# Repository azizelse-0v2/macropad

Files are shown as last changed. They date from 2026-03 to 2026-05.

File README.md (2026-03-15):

# Macro Pad

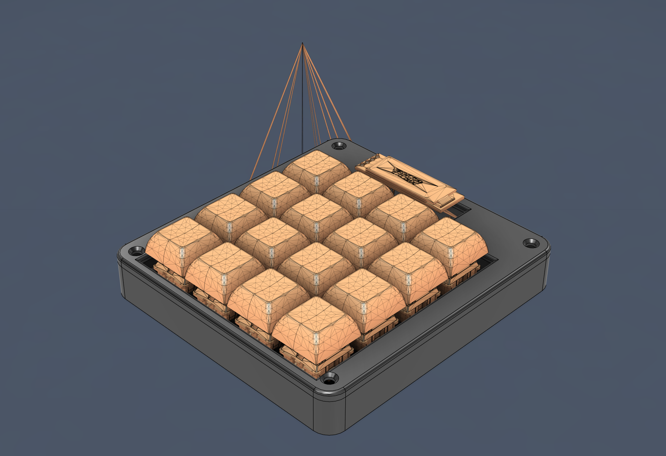
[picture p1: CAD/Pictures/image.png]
Macro Pad


A custom macro pad featuring 16 mechanical switches, OLED display, and RGB LEDs. Built with the Seeed XIAO RP2040 microcontroller and KMK firmware for a compact, programmable keyboard solution.

## Features

- **4 Cherry MX Switches**: Tactile mechanical switches for responsive key presses
- **0.96" OLED Display**: SH1106 I2C display for status or custom graphics
- **RGB LED Matrix**: WS2812B LEDs for visual feedback
- **Compact Design**: Fits within 200x200x100mm enclosure
- **KMK Firmware**: Python-based firmware for easy customization

## Images

### Schematic
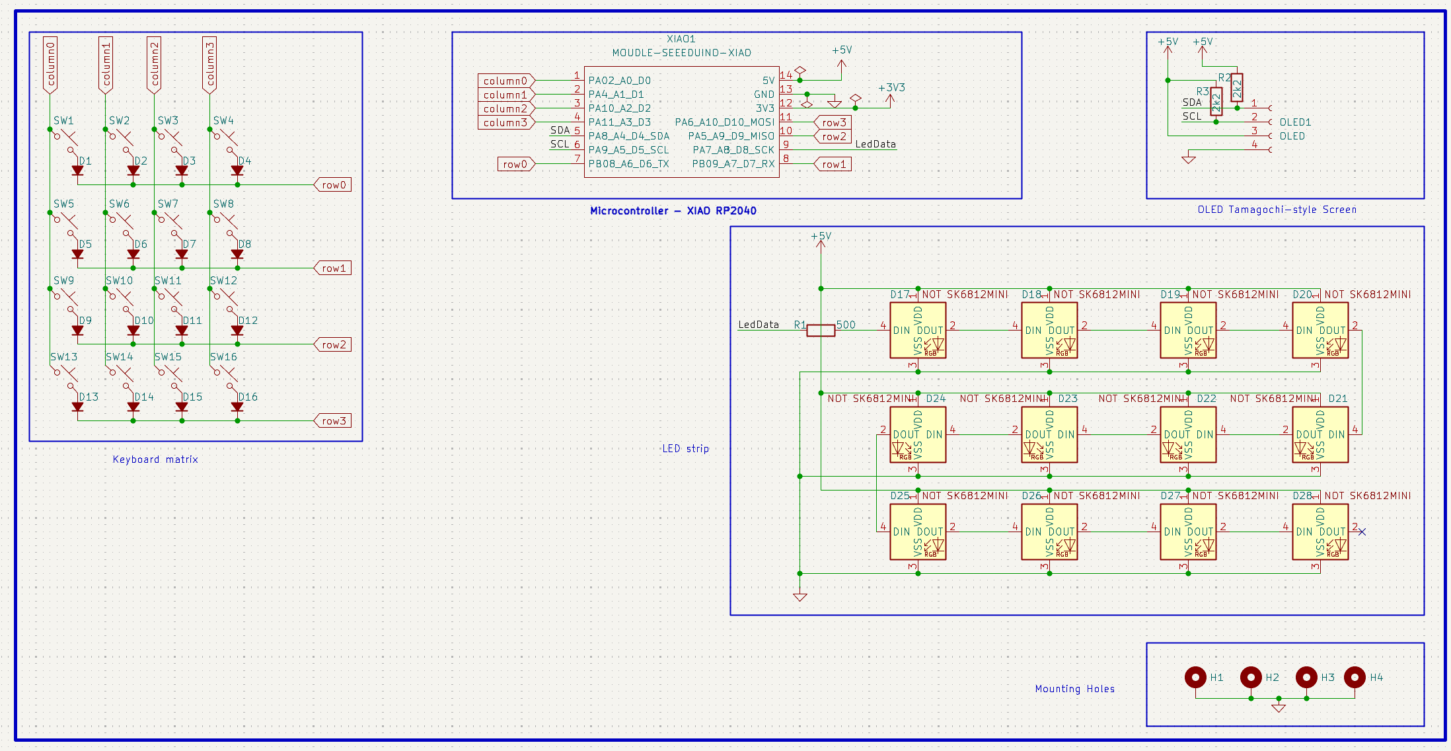
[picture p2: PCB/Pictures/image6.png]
Schematic


### PCB Layout
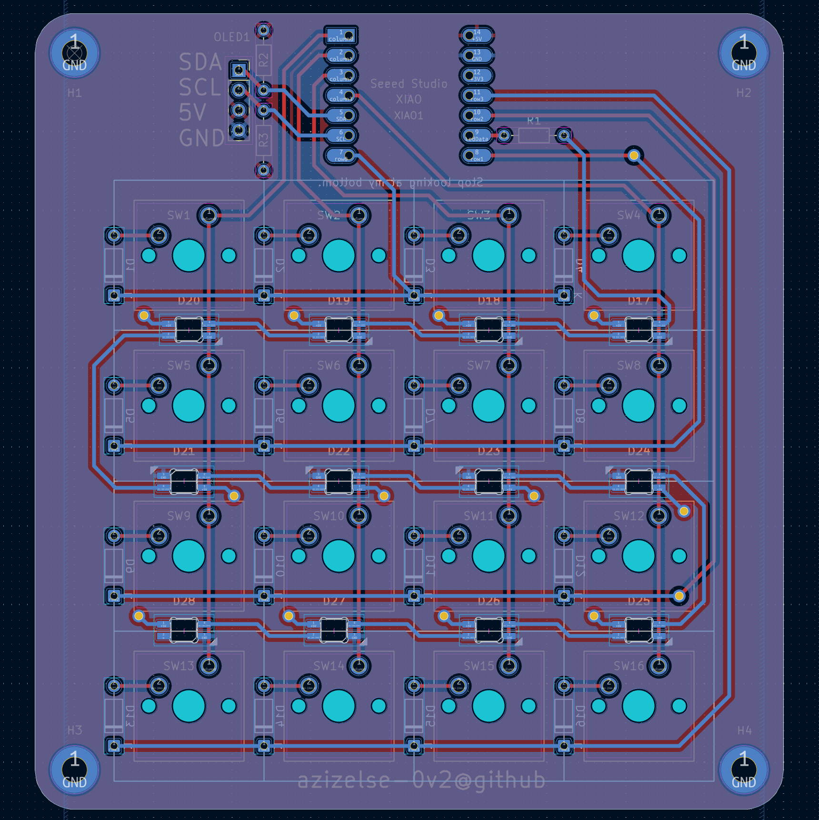
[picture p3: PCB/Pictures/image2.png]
PCB


### Case Assembly
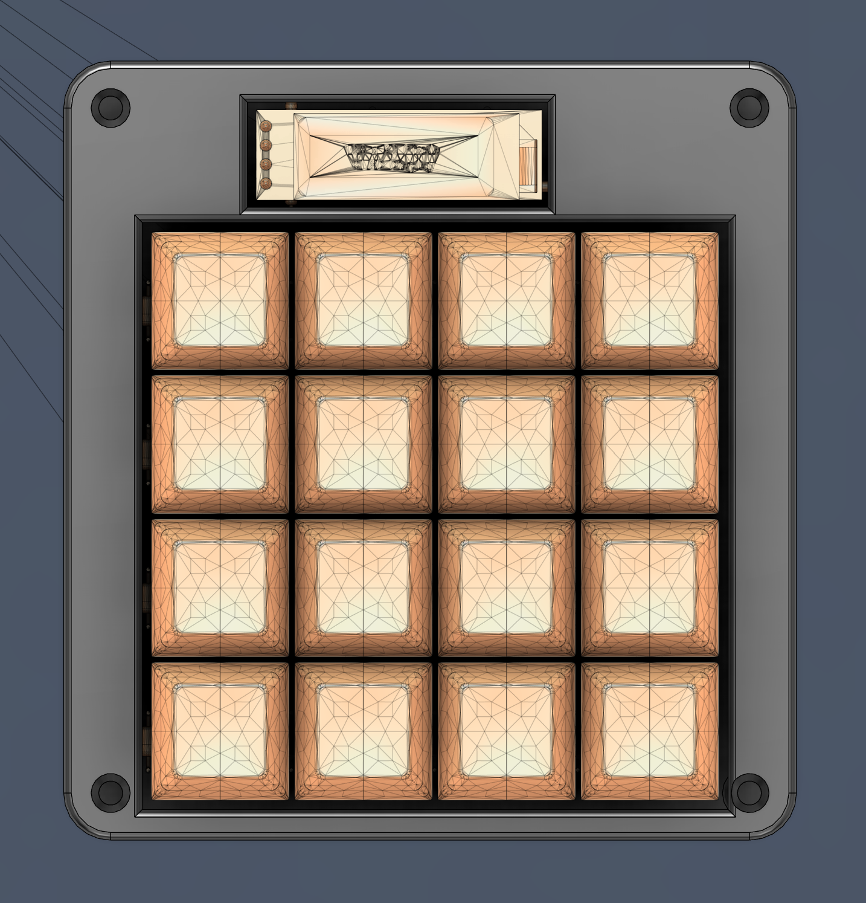
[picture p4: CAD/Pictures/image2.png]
Case Assembly


## Bill of Materials (BOM)

| Part | Quantity | Description | Supplier |
|---|---|---|---|
| Seeed XIAO RP2040 | 1 | RP2040 microcontroller board | Seeed Studio |
| Cherry MX Switch | 16 | Mechanical keyboard switches | Cherry |
| DSA Keycaps | 16 | Cherry MX compatible keycaps | Keycaps Direct |
| 0.96" OLED Display | 1 | SH1106 128x64 I2C OLED | AliExpress |
| SK6812 MINI-E LED | 12 | RGB LEDs | AliExpress |
| Custom PCB | 1 | 2-layer PCB | This project |
| 3D Printed Case | 2 | ABS/PLA case parts | This project |

## Project Structure

```
macro_pad/
├── CAD/                 # 3D models and assembly
│   ├── bottom_part.step # Bottom part of the 3D model
│   ├── top_part.step    # Top part of the 3D model
│   └── Pictures/        # Rendered images
├── PCB/                 # KiCAD design files
│   ├── macro_pad.kicad_pro
│   ├── macro_pad.kicad_sch
│   ├── macro_pad.kicad_pcb
│   └── Pictures/        # PCB images
├── Firmware/            # KMK firmware source
│   ├── main.py
│   └── kmk/             # KMK library
├── Production/          # Manufacturing files
│   ├── gerbers.zip      # PCB gerbers
│   ├── top_part.STL     # Case parts
│   ├── bottom_part.STL
│   └── firmware.uf2     # Compiled firmware
└── README.md
```

## Building the Macro Pad

### PCB Manufacturing
1. Download `Production/gerbers.zip`
2. Upload to your preferred PCB manufacturer (JLCPCB, PCBWay, etc.)
3. Order 2-layer PCBs with standard specifications

### Case Printing
1. Use the STL files in `Production/` for 3D printing
2. Print with ABS or PLA, 0.2mm layer height recommended
3. Assemble with M3 screws

### Assembly
1. Solder components to the PCB
2. Mount switches
3. Connect OLED and LEDs
4. Place PCB in case and secure

### Firmware Flashing
1. Install KMK firmware (see Firmware/ directory)
2. Put XIAO RP2040 into bootloader mode (double-click reset)
3. Drag `firmware.uf2` to the RPI-RP2 drive

## Customization

The firmware is written in Python using KMK. Edit `Firmware/main.py` to customize key mappings, LED effects, and display output.

## Repository

- **GitHub**: [azizelse/macro_pad](https://github.com/azizelse/macro_pad)
- **License**: MIT

## Acknowledgments

This project is submitted as part of the Hackpad community challenge. Special thanks to the KMK firmware developers and the open-source hardware community.

---

*Built with ❤️ using KiCAD, Fusion 360, and KMK*

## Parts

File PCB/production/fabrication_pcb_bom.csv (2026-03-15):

Designator | Footprint | Quantity | Value | LCSC Part #
D1, D10, D11, D12, D13, D14, D15, D16, D2, D3, D4, D5, D6, D7, D8, D9 | D_DO-35_SOD27_P7.62mm_Horizontal | 16 | D_Small_Filled
D17, D18, D19, D20, D21, D22, D23, D24, D25, D26, D27, D28 | SK6812MINI-E_fixed | 12 | SK6812MINI-E
OLED1 | PinSocket_1x04_P2.54mm_Vertical | 1 | OLED
R1 | R_Axial_DIN0204_L3.6mm_D1.6mm_P7.62mm_Horizontal | 1 | 500
R2, R3 | R_Axial_DIN0204_L3.6mm_D1.6mm_P7.62mm_Horizontal | 2 | 2k2
SW1, SW10, SW11, SW12, SW13, SW14, SW15, SW16, SW2, SW3, SW4, SW5, SW6, SW7, SW8, SW9 | SW_Cherry_MX_1.00u_PCB | 16 | SW_Push_45deg
XIAO1 | XIAO_RP2040 | 1 | MOUDLE-SEEEDUINO-XIAO

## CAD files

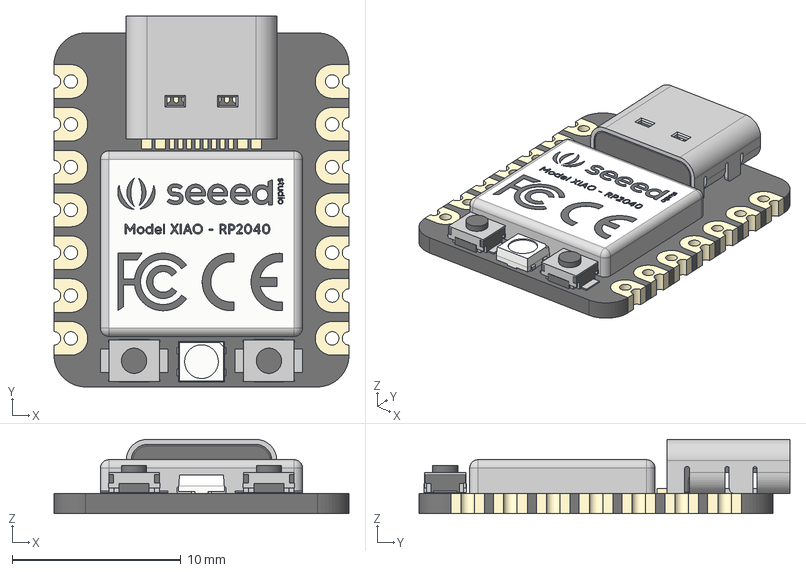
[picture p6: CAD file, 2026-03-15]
PCB/Deps/XIAO_RP2040.step
17.5 x 22.0 x 4.40 mm
type-c v2
smd_button v3
DOUT
DIN
VSS
VDD
smd_button v3(Mirror)

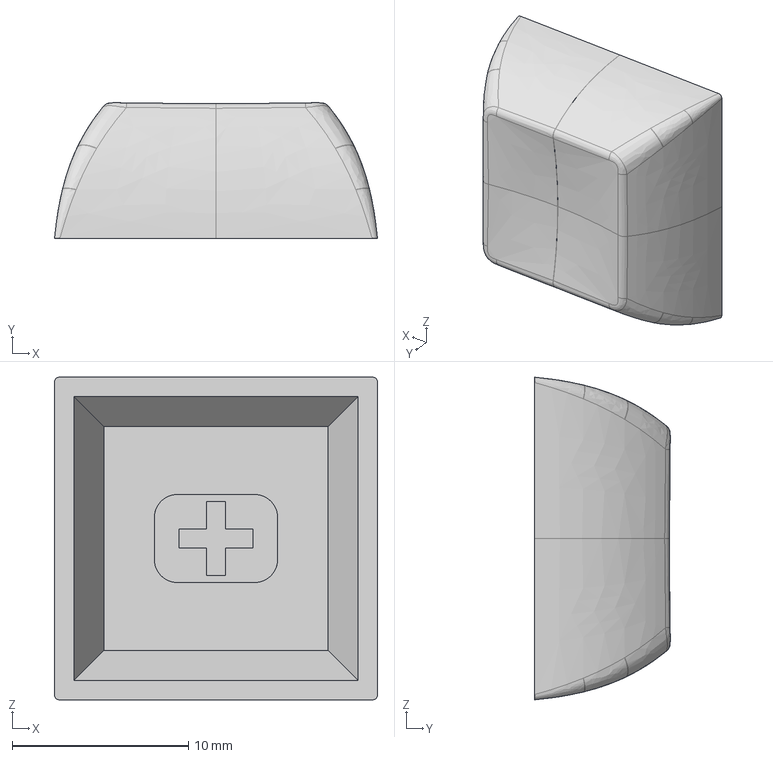
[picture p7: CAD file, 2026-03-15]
PCB/Deps/DSA_Keycap_CherryMX.step
18.3 x 7.69 x 18.3 mm

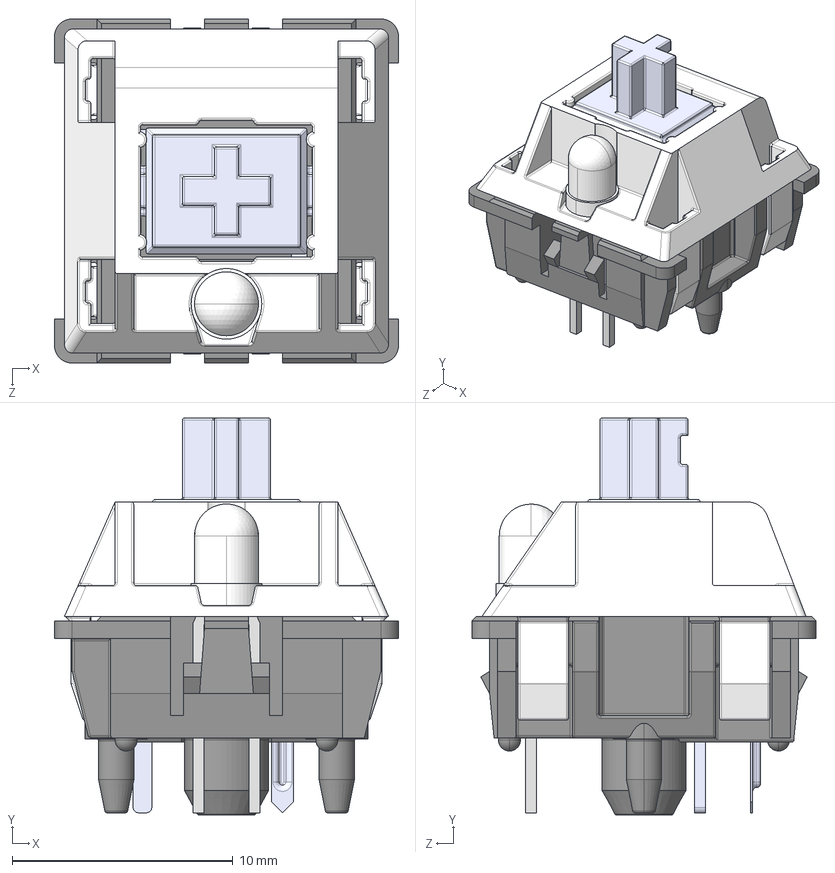
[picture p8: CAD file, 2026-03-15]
PCB/Deps/Cherry_MX_Switch.STEP
15.6 x 18.0 x 15.6 mm
Bottom
Pulsador
Top
Pieza5^Cherry MX
Pin1
Pin2
Led 3mm_trans

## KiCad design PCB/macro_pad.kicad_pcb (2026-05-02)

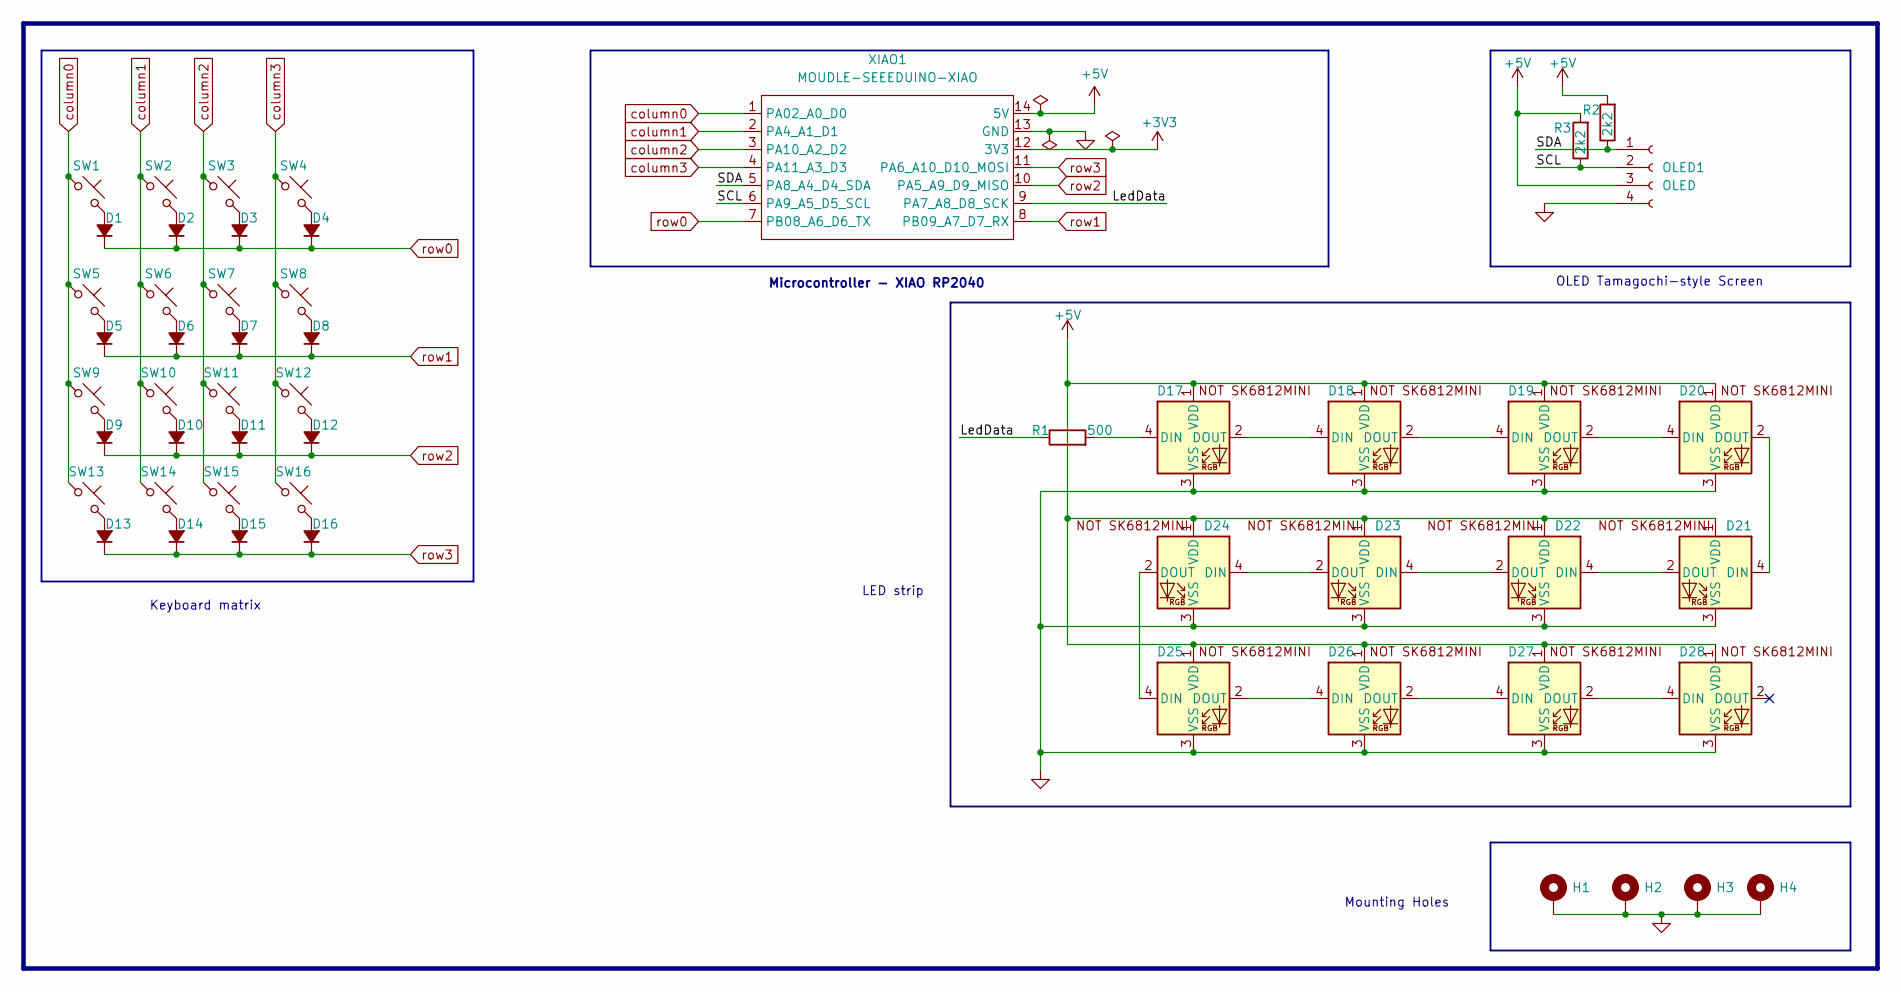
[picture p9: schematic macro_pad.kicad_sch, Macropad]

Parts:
D1, D2, D3, D4, D5, D6, D7, D8, D9, D10, D11, D12, D13, D14, D15, D16: D_Small_Filled; D_DO-35_SOD27_P7.62mm_Horizontal
D17, D18, D19, D20, D21, D22, D23, D24, D25, D26, D27, D28: SK6812MINI-E; SK6812MINI-E_fixed
H1, H2, H3, H4: MountingHole_Pad; MountingHole_3.2mm_M3_ISO7380_Pad
OLED1: OLED; PinSocket_1x04_P2.54mm_Vertical
R1: 500; R_Axial_DIN0204_L3.6mm_D1.6mm_P7.62mm_Horizontal
R2, R3: 2k2; R_Axial_DIN0204_L3.6mm_D1.6mm_P7.62mm_Horizontal
SW1, SW2, SW3, SW4, SW5, SW6, SW7, SW8, SW9, SW10, SW11, SW12, SW13, SW14, SW15, SW16: SW_Push_45deg; SW_Cherry_MX_1.00u_PCB
XIAO1: MOUDLE-SEEEDUINO-XIAO; XIAO_RP2040

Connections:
+3V3: XIAO1.12 (3V3)
+5V: D17.1 (VDD), D18.1 (VDD), D19.1 (VDD), D20.1 (VDD), D21.1 (VDD), D22.1 (VDD), D23.1 (VDD), D24.1 (VDD), D25.1 (VDD), D26.1 (VDD), D27.1 (VDD), D28.1 (VDD), OLED1.3, R2.2, R3.2, XIAO1.14 (5V)
/LedData: R1.1, XIAO1.9 (PA7_A8_D8_SCK)
/SCL: OLED1.2, R3.1, XIAO1.6 (PA9_A5_D5_SCL)
/SDA: OLED1.1, R2.1, XIAO1.5 (PA8_A4_D4_SDA)
GND: D17.3 (VSS), D18.3 (VSS), D19.3 (VSS), D20.3 (VSS), D21.3 (VSS), D22.3 (VSS), D23.3 (VSS), D24.3 (VSS), D25.3 (VSS), D26.3 (VSS), D27.3 (VSS), D28.3 (VSS), H1.1, H2.1, H3.1, H4.1, OLED1.4, XIAO1.13 (GND)
unnamed: D1.2 (A), SW1.2
unnamed: D2.2 (A), SW2.2
unnamed: D3.2 (A), SW3.2
unnamed: D4.2 (A), SW4.2
unnamed: D5.2 (A), SW5.2
unnamed: D6.2 (A), SW6.2
unnamed: D7.2 (A), SW7.2
unnamed: D8.2 (A), SW8.2
unnamed: D9.2 (A), SW9.2
unnamed: D10.2 (A), SW10.2
unnamed: D11.2 (A), SW11.2
unnamed: D12.2 (A), SW12.2
unnamed: D13.2 (A), SW13.2
unnamed: D14.2 (A), SW14.2
unnamed: D15.2 (A), SW15.2
unnamed: D16.2 (A), SW16.2
unnamed: D17.4 (DIN), R1.2
unnamed: D17.2 (DOUT), D18.4 (DIN)
unnamed: D18.2 (DOUT), D19.4 (DIN)
unnamed: D19.2 (DOUT), D20.4 (DIN)
unnamed: D20.2 (DOUT), D21.4 (DIN)
unnamed: D21.2 (DOUT), D22.4 (DIN)
unnamed: D22.2 (DOUT), D23.4 (DIN)
unnamed: D23.2 (DOUT), D24.4 (DIN)
unnamed: D24.2 (DOUT), D25.4 (DIN)
unnamed: D25.2 (DOUT), D26.4 (DIN)
unnamed: D26.2 (DOUT), D27.4 (DIN)
unnamed: D27.2 (DOUT), D28.4 (DIN)
column0: SW1.1, SW5.1, SW9.1, SW13.1, XIAO1.1 (PA02_A0_D0)
column1: SW2.1, SW6.1, SW10.1, SW14.1, XIAO1.2 (PA4_A1_D1)
column2: SW3.1, SW7.1, SW11.1, SW15.1, XIAO1.3 (PA10_A2_D2)
column3: SW4.1, SW8.1, SW12.1, SW16.1, XIAO1.4 (PA11_A3_D3)
row0: D1.1 (K), D2.1 (K), D3.1 (K), D4.1 (K), XIAO1.7 (PB08_A6_D6_TX)
row1: D5.1 (K), D6.1 (K), D7.1 (K), D8.1 (K), XIAO1.8 (PB09_A7_D7_RX)
row2: D9.1 (K), D10.1 (K), D11.1 (K), D12.1 (K), XIAO1.10 (PA5_A9_D9_MISO)
row3: D13.1 (K), D14.1 (K), D15.1 (K), D16.1 (K), XIAO1.11 (PA6_A10_D10_MOSI)

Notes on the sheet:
Microcontroller - XIAO RP2040
Keyboard matrix
LED strip
Mounting Holes
OLED Tamagochi-style Screen

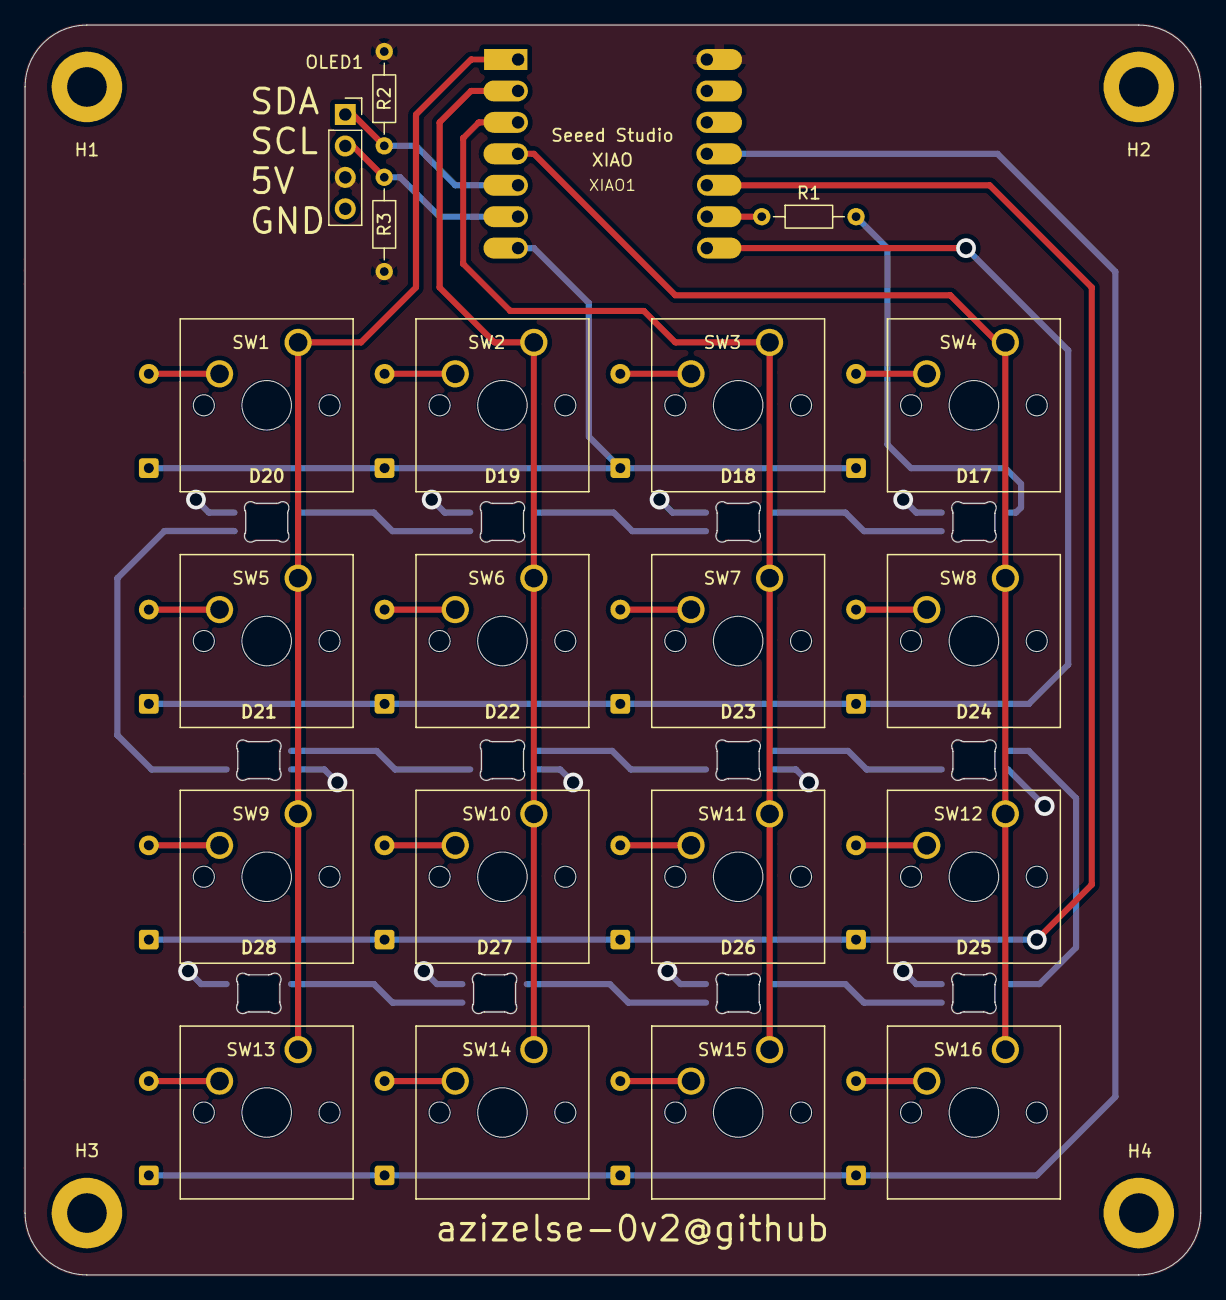
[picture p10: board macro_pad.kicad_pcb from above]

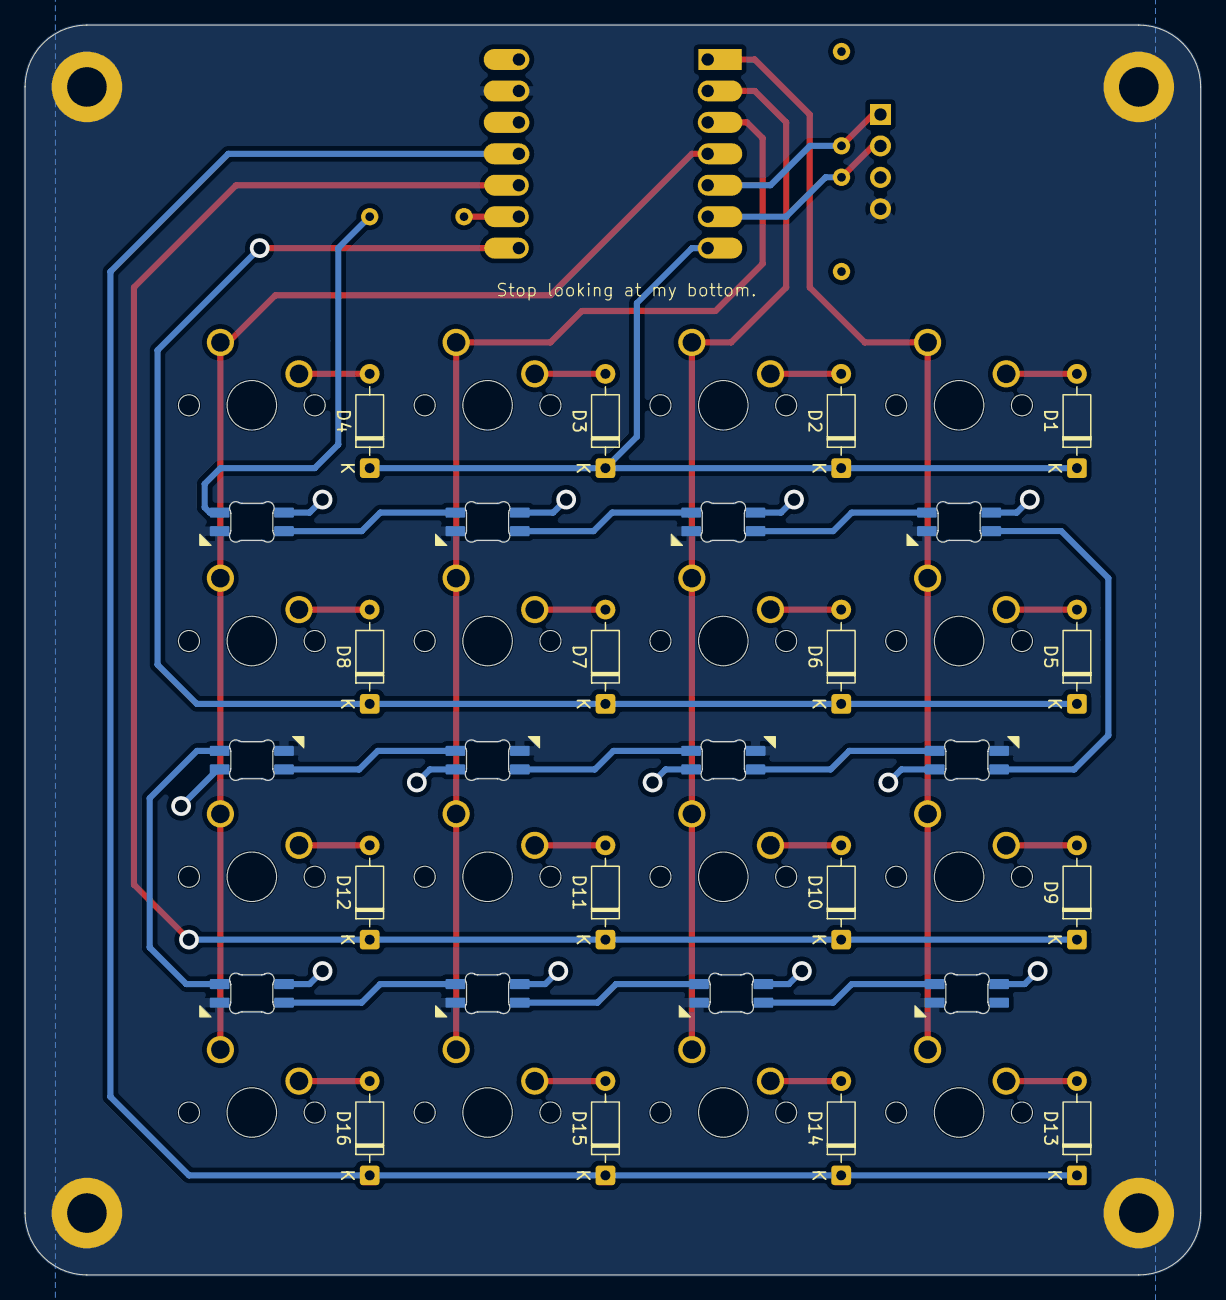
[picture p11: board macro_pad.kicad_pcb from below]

Board: 2 copper layers, 95.0 x 101.0 mm, 53 parts (16 on the bottom side), 41 nets.

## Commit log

2026-03-01 Improved design
    [macro_pad.kicad_pcb, macro_pad.kicad_sch]
2026-03-03 Added mounting holes
    [macro_pad.kicad_pcb, macro_pad.kicad_sch]
2026-03-03 Uploaded firmware and removed backups
    [macro_pad.kicad_pcb, macro_pad.kicad_sch]
2026-03-04 Added Frame and Firmware
    [Frame.stl, macro_pad.kicad_pcb]
2026-03-04 Modified Frame
    [Frame.stl]
2026-03-12 Modified frame & schem
    [Frame.stl]
2026-03-15 Followed guidelines on schem
    [Cherry_MX_Switch.STEP, DSA_Keycap_CherryMX.step, XIAO_RP2040.step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]
2026-03-15 Changed Microcontroller and size of pcb
    [macro_pad.kicad_pcb]
2026-03-15 Finalised CAD
    [Frame.stl, bottom_part.stl, top_part.stl]
2026-03-15 Added README.md and pictures
    [bottom_part.stl, macro_pad.kicad_pcb, top_part.stl]
2026-03-15 Removed unnecessary firmware files and generated pcb production files
    [fabrication_pcb_bom.csv, fabrication_pcb_designators.csv, fabrication_pcb_positions.csv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]
2026-05-02 Finalized everything
    [bottom_part.stl, macro_pad.kicad_pcb, macro_pad.kicad_sch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]
